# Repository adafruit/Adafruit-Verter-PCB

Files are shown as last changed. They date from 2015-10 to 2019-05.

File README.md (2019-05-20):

## Adafruit Verter Buck/Boost Breakout PCB
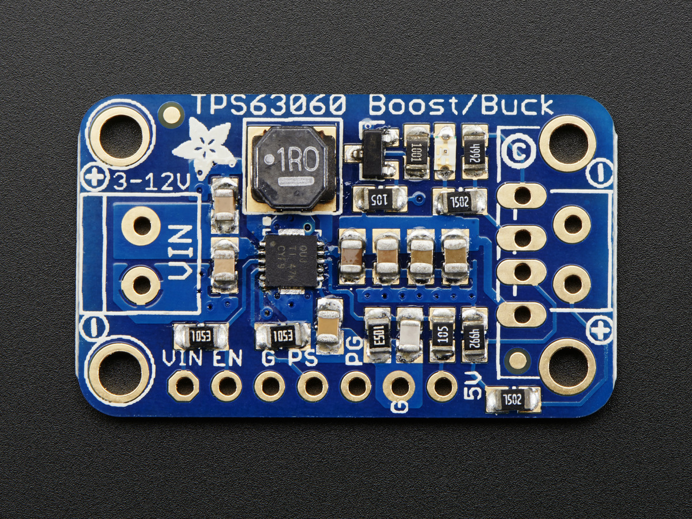
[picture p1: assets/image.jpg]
<a href="http://www.adafruit.com/products/2190"><br/>
Click here to purchase one from the Adafruit shop</a>

Convert just about any battery pack to 5V with VERTER - our fresh new Buck-Boost power converter. VERTER can take battery voltages from 3-12VDC and output a nice 5V DC, which makes it a perfect universal power supply for your portable project! Where Verter really shines is when you have a battery or power range that can fluctuate a lot, or you don't know what you'll end up using.

It operates smoothly over the 3-12V range, moving from a boost converter (3-5V in) to a buck converter (5-12V in) on the fly. Please note! This chip can do both, but it really works better as a buck converter than a boost. If you need a full 500mA out, it will struggle as it gets down to 3V and the output will sag to about 4.8V (which is still within standard USB power specs). If you only need something to boost a voltage up to 5V and you want it to be really good at it, check out our PowerBoost series, which excel at that.

Like our popular 5V 1A USB wall adapter, we tweaked the output to be 5.2V instead of a straight-up 5.0V so that there's a little bit of 'headroom' long cables, high draw, the addition of a diode on the output if you wish, etc. The 5.2V is safe for all 5V-powered electronics like Arduino, Raspberry Pi, or Beagle Bone while preventing icky brown-outs during high current draw because of USB cable resistance.

PCB files for the Verter Buck/Boost Breakout
- https://www.adafruit.com/products/2190

### License

Adafruit invests time and resources providing this open source design, please support Adafruit and open-source hardware by purchasing products from [Adafruit](https://www.adafruit.com)!

All text above must be included in any redistribution

Designed by Limor Fried/Ladyada for Adafruit Industries.
Creative Commons Attribution/Share-Alike, all text above must be included in any redistribution. 
See license.txt for additional information.

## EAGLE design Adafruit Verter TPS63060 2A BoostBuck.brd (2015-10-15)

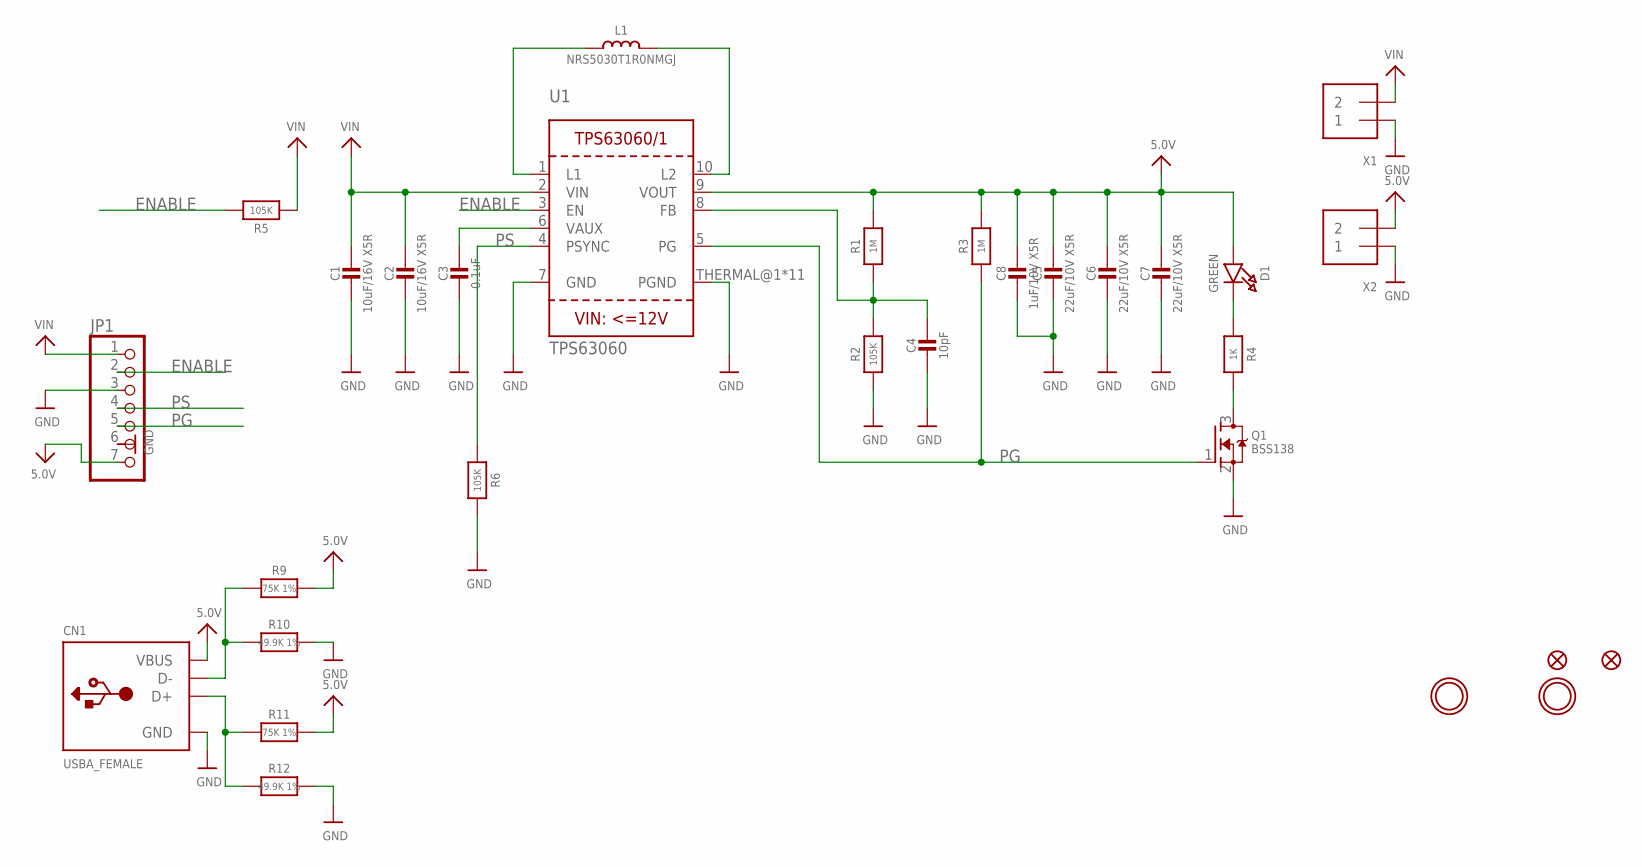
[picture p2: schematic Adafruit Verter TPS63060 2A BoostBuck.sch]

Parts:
C1, C2: 10uF/16V X5R; 0805-NO
C3: 0.1uF; 0805-NO
C4: 10pF; 0805-NO
C5, C6, C7: 22uF/10V X5R; 0805-NO
C8: 1uF/10V X5R; 0805-NO
CN1: USBA_FEMALE; USB_HOST-PTH
D1: GREEN; CHIPLED_0805_NOOUTLINE
FID1, FID2: FIDUCIAL""; FIDUCIAL_1MM
JP1: HEADER-1X770MIL; 1X07_ROUND_70
L1: NRS5030T1R0NMGJ; INDUCTOR_5X5MM_TDK_VLC5045
Q1: BSS138; SOT23-WIDE
R1, R3: 1M; 0805-NO
R2, R5, R6: 105K; 0805-NO
R4: 1K; 0805-NO
R9, R11: 75K 1%; 0805-NO
R10, R12: 49.9K 1%; 0805-NO
U1: TPS63060; PWSON-N10
U$15, U$17: MOUNTINGHOLE2.5; MOUNTINGHOLE_2.5_PLATED
X1, X2: TERMBLOCK_1X2; TERMBLOCK_1X2-3.5MM

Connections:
5.0V: C5.1, C6.1, C7.1, C8.1, CN1.VBUS, D1.A, JP1.7, R1.2, R3.2, R9.2, R11.2, U1.9 (VOUT), X2.2
D+: CN1.D+, R11.1, R12.1
D-: CN1.D-, R9.1, R10.1
ENABLE: JP1.2, R5.2, U1.3 (EN)
GND: C1.2, C2.2, C3.2, C4.2, C5.2, C6.2, C7.2, C8.2, CN1.GND, JP1.3, JP1.6, Q1.2 (S), R2.1, R6.2, R10.2, R12.2, U1.7 (GND), U1.THERMAL@1 (PGND), U1.THERMAL@5 (PGND), U1.THERMAL@6 (PGND), U1.THERMAL@7 (PGND), U1.THERMAL@8 (PGND), U1.THERMAL@9 (PGND), U1.THERMAL@10 (PGND), U1.THERMAL@11 (PGND), U1.THERMAL@12 (PGND), U1.THERMAL@13 (PGND), U1.THERMAL@14 (PGND), X1.1, X2.1
unnamed: L1.P$1 (1), U1.1 (L1)
unnamed: L1.P$2 (2), U1.10 (L2)
unnamed: C3.1, U1.6 (VAUX)
unnamed: D1.C, R4.1
unnamed: C4.1, R1.1, R2.2, U1.8 (FB)
unnamed: Q1.3 (D), R4.2
PG: JP1.5, Q1.1 (G), R3.1, U1.5 (PG)
PS: JP1.4, R6.1, U1.4 (PSYNC)
VIN: C1.1, C2.1, JP1.1, R5.1, U1.2 (VIN), X1.2

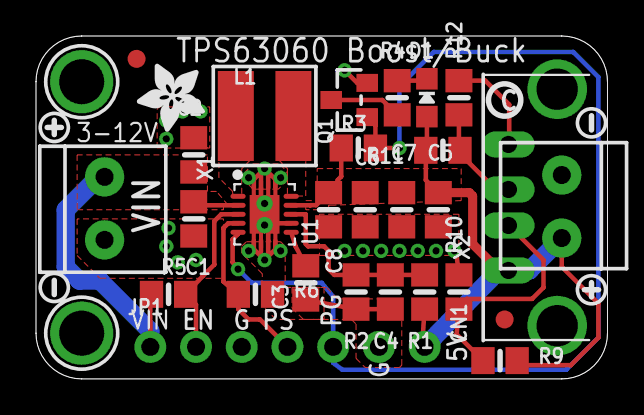
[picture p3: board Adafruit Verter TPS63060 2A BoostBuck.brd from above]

Board: 2 copper layers, 31.8 x 19.1 mm, 37 parts (1 on the bottom side), 14 nets.

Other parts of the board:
U$22, U$23: SYMBOL_PLUS
U$24, U$25: SYMBOL_MINUS
U$27: ADAFRUIT_3.5MM
U$37: VERTERLOGO
U$38: PCBFEAT-REV-040

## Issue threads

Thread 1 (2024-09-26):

Schematic PDF?

RoaCode, 2024-09-26:
Is it worth publishing a PDF view of the schematic for quick viewing? I found myself with questions about this board on a machine without Eagle, and while I was able to view through online tools, I could share the resulting PDF to save the next person a few clicks. It seems like other Adafruit PCBs have some sort of schematic view, whether PDF or PNG, etc.

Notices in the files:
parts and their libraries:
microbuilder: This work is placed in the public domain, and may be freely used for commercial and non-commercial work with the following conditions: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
